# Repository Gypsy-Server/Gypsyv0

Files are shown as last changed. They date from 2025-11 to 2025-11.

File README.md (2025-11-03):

  
*A local file viewer built on the ESP8266*

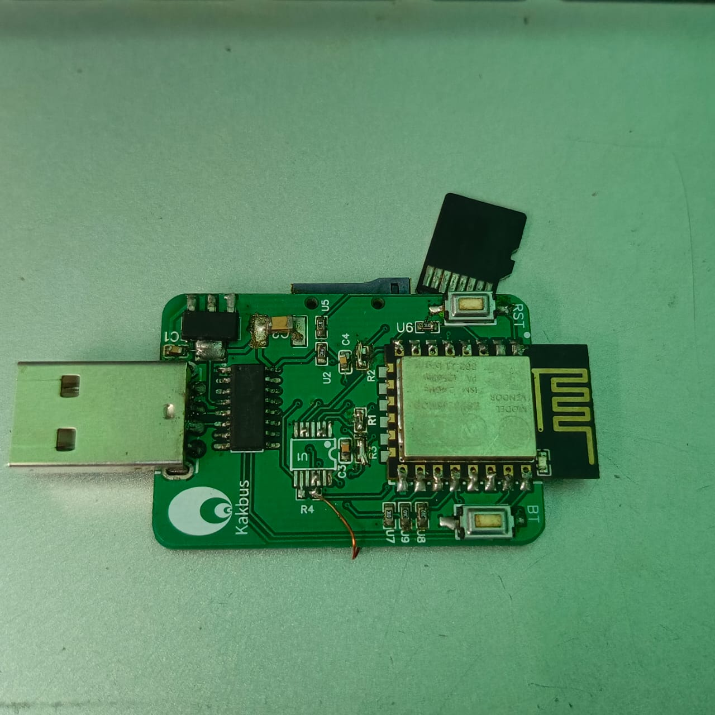
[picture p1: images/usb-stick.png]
Board Preview


---

## What is here

- **Local file browsing** over Wi-Fi  
- **SD card (FAT32/MBR)** storage support   
- Runs standalone — powered via USB or external 5 V  or 3.3V

---

## Hardware

- **MCU:** ESP8266(12E)
- **Storage:** SD card(SPI MODE)  
- **Voltage Regulator AMS117 3.3V**
- **Ch340C USB TO TTL Converter chip**
- **Passive Components:** Resistor ,Capacitor

You can view the full schematic and PCB in the `usb_stick_kicadfiles/` folder (KiCad project).

---

##  What to do 

1. Flash gypsy.ino using Arduino IDE or PlatformIO.  
2. Open Serial Monitor to get the IP (eg 192.168.x.x)
3. Open in any browser on Computer or any device connected to that Network

---
## What you will see

Home Page
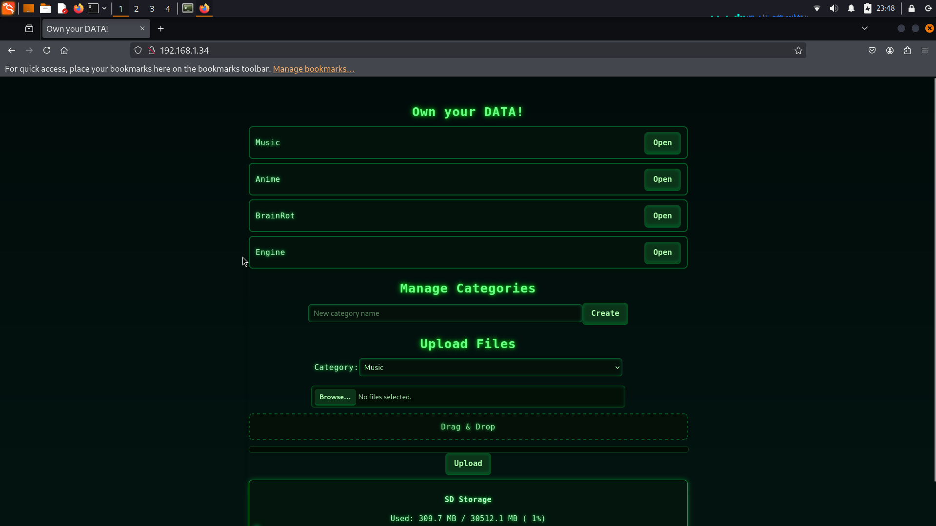
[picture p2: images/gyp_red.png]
Home Page


File viewing 
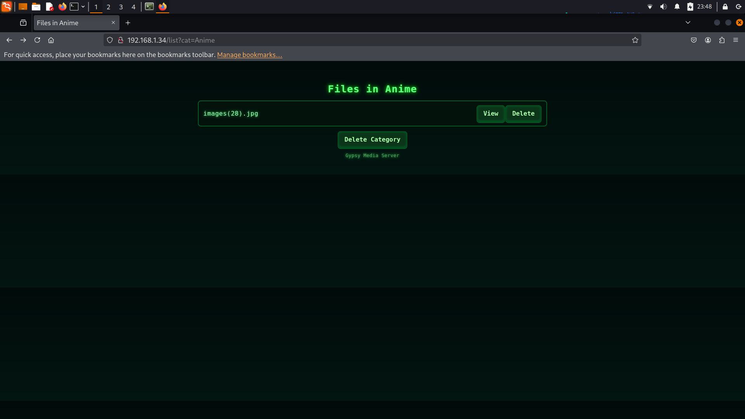
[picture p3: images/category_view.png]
File Handling

 
 Contents
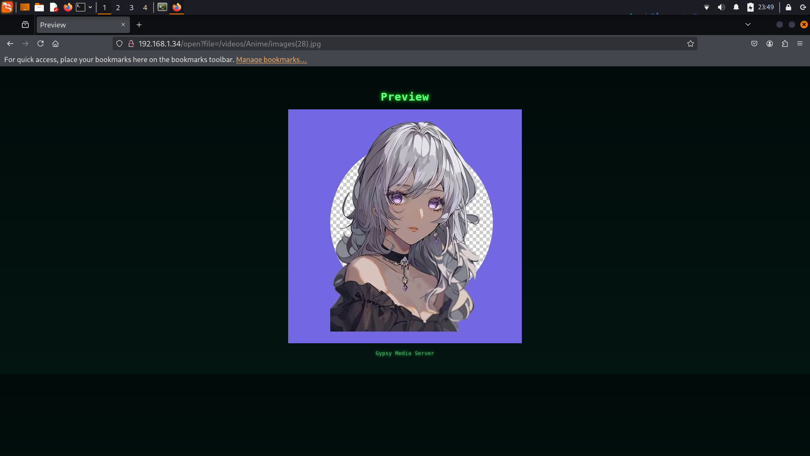
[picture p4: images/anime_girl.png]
Anime girl

 
 Mp4 full screen view
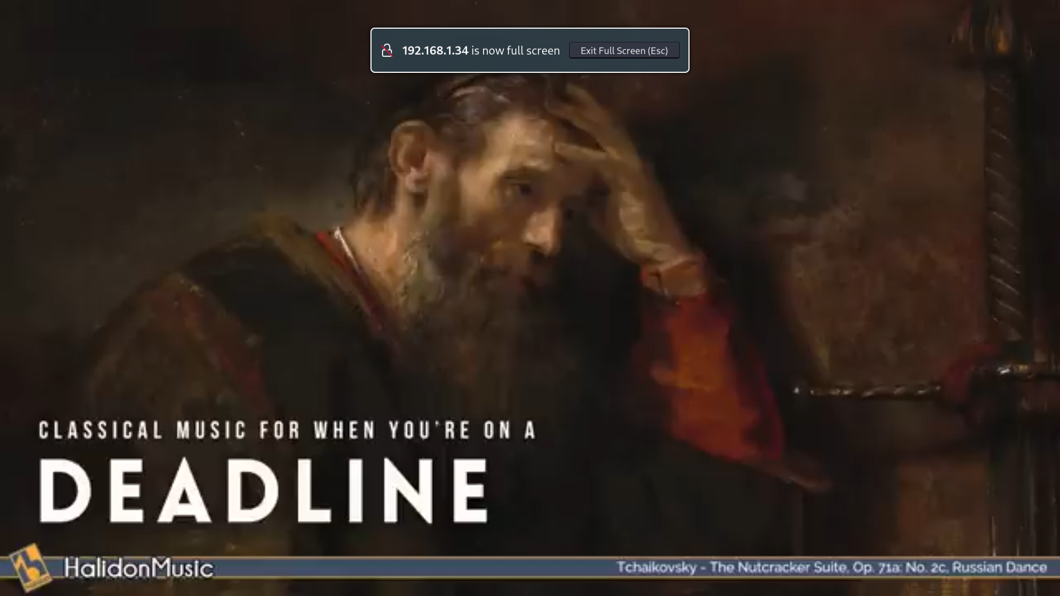
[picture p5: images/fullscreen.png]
Full screen Mp3


## What i have seen SO FAR
- file uploading speed is Limited (average 150-250KB/s)
- Slower playing Larger files (greater than 50MB)
- but Good in MP3 handling , doesn't stuck (80KB of RAM is sufficient in ths case)
- Sometimes SD card initialization fails (random)

## Some Fatal Issues 
- **The original PCB has fatal a flaw, SD card Chip detect Pin as CS PIN , so don't use this project as it is , Also the Driver chip of sd card is 
not necessary so for better design remove it esp8266 can drive sd card itself by 3.3v logic, for my case i have used and extra thin wire
to cover up my mistake**
so i would recommend to use this project [Hackstar-io](https://www.hackster.io/Neutrino-1/wireless-sd-card-reader-esp8266-de7f07)
for the Hardware Layout

**Mistakes**
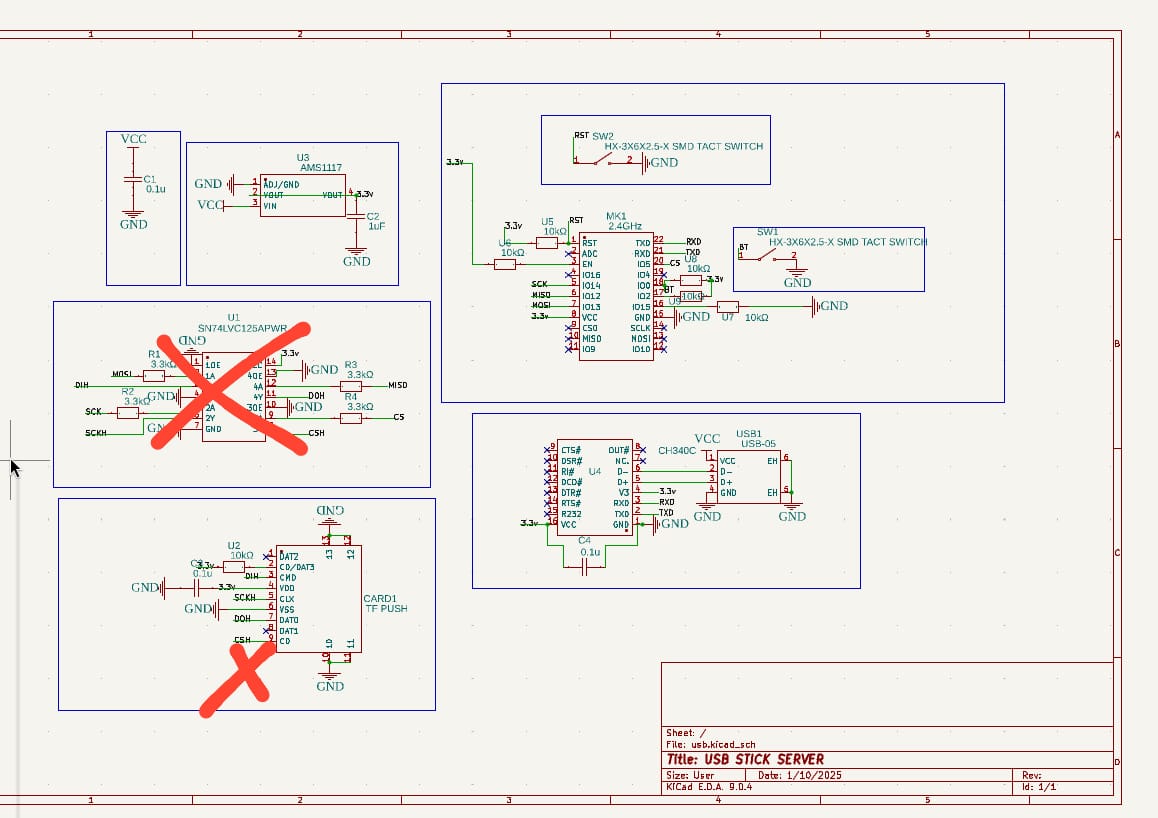
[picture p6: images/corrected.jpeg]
Wrong Schematic


##  What I’m Exploring Next

- Network sharing (I have tested it with Ngrok proxy tunneling to my friends , but if multiple people use at same time then it stops)  
- ESP32 port for faster WIFI throughput  
- Power optimization and case design( even smaller any small processor like Raspberry Pi Zero or ESP32 higher variant)
- Larger Video playback(cinema of Some Sort)

---

##  Feedback Wanted

This is still a **work in progress**, and I’d love your thoughts on:

- Firmware structure and web interface flow  
- PCB layout or power-handling tips  
- Ideas for extending it into a full mini NAS

If you’ve built anything similar — or see a way to make this smarter, faster, or cleaner — I’m all ears.

---

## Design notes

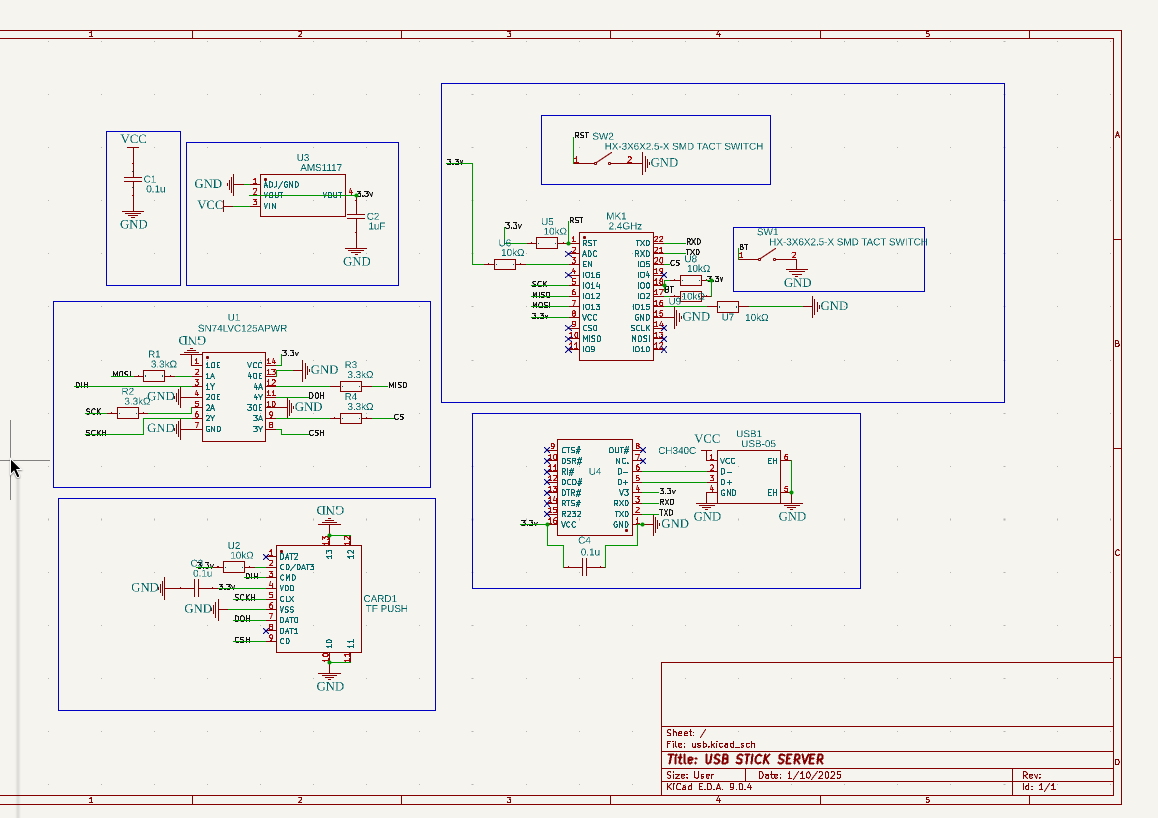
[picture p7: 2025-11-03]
images/usbstick.png

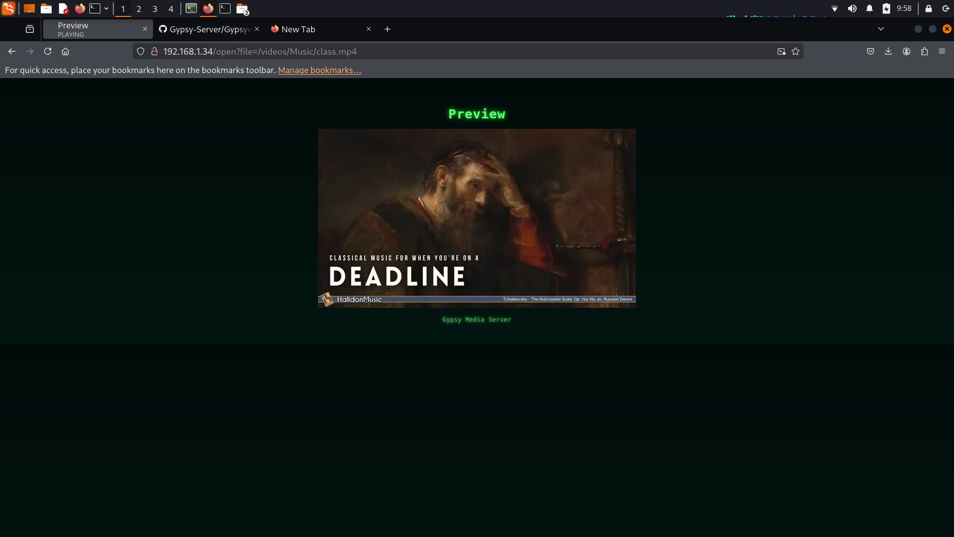
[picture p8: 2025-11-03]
images/mp4_playing.png

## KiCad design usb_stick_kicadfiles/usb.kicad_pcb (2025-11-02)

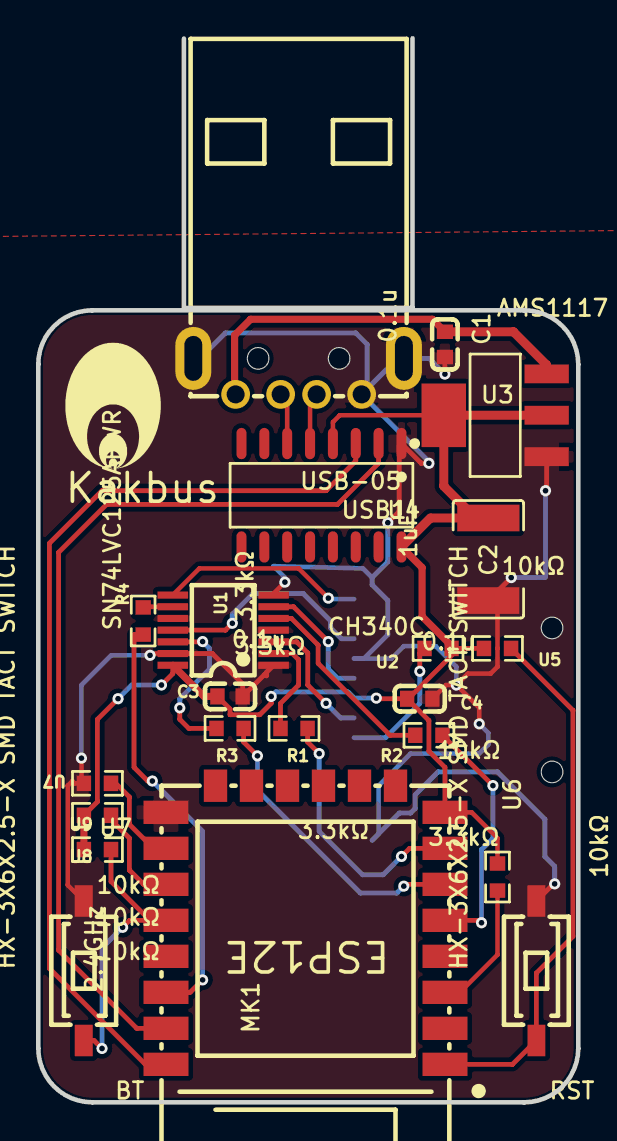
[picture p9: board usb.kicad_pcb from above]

Board: 2 copper layers, 30.0 x 44.0 mm, 22 parts (1 on the bottom side), 25 nets.

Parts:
BT: HX-3X6X2.5-X SMD TACT SWITCH; SW-SMD_HX-3X6X2.5-X
C1, C3, C4: 0.1u; C0603
C2: 1uF; C1812
CARD1: TF PUSH; TF-SMD_TF-PUSH
MK1: 2.4GHz; WIFIM-SMD_ESP-12E-BR
R1, R2, R3, R4: 3.3kΩ; R0603
RST: HX-3X6X2.5-X SMD TACT SWITCH; SW-SMD_HX-3X6X2.5-X
U1: SN74LVC125APWR; TSSOP-14_L5.0-W4.4-P0.65-LS6.4-BL
U2, U5, U6, U7, U8, U9: 10kΩ; R0603
U3: AMS1117; SOT-223_L6.5-W3.5-P2.30-LS7.0-BR
U4: CH340C; SOP-16_L10.0-W3.9-P1.27-LS6.0-BL
USB1: USB-05; USB-A-TH_USB-05

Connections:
3.3V: C2.2, C3.1, C4.1, CARD1.4, MK1.8, U1.14, U2.1, U3.2, U3.4, U4.4, U4.16, U5.1, U6.1, U8.2, U9.2
BT: BT.1, MK1.18, U8.1
CARD1_2: CARD1.2, U2.2
CS: MK1.20, R4.2
CSH: CARD1.CD, U1.8
DIH: CARD1.3, U1.3
DOH: CARD1.7, U1.11
GND: BT.2, C1.1, C2.1, C3.2, C4.2, CARD1.6, CARD1.10, CARD1.11, CARD1.12, CARD1.13, MK1.15, RST.2, U1.1, U1.4, U1.7, U1.10, U1.13, U3.1, U4.1, U7.2, USB1.4, USB1.5, USB1.6
MISO: MK1.6, R3.2
MK1_3: MK1.3, U6.2
MK1_16: MK1.16, U7.1
MK1_17: MK1.17, U9.1
MOSI: MK1.7, R1.1
RST: MK1.1, RST.1, U5.2
RXD: MK1.22, U4.3
SCK: MK1.5, R2.1
SCKH: CARD1.5, U1.6
TXD: MK1.21, U4.2
U1_2: R1.2, U1.2
U1_5: R2.2, U1.5
U1_9: R4.1, U1.9
U1_12: R3.1, U1.12
U4_5: U4.5, USB1.3
U4_6: U4.6, USB1.2
VCC: C1.2, U3.3, USB1.1

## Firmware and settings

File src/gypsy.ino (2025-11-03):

/*
 * Gypsy version 0 (basic version), open for everyone to try and give a feedback
 * 
 * 
 * 
 * 
 * 
 * 
 * Using SD card as a Fat32 File System to store content , And accessing it through our local network via ESP8266 in DHCP mode 
Router is necessary , If you don't have router then There will be a Access point mode version 
 * format sd card to FAT32 MBR before using it

It was originally a Platformio project , converted in a single file for quick upload and test
 */


#include <ESP8266WiFi.h>
#include <ESP8266WebServer.h>
#include <SdFat.h>

#define SD_CS_PIN 5 //IF YOU HAVE ANY OTHER SPARE GPIO USE THAT 

const char* ssid = "Enter your Network id here";
const char* password = "your network password";

ESP8266WebServer server(80);
SdFat32 SD;

volatile bool isClientStreaming = false;
volatile bool isUploading = false;
File32 upFile; 

String cleanName(String s) {
  s.replace("..", "");
  while (s.startsWith("/")) s.remove(0, 1);
  while (s.endsWith("/")) s.remove(s.length() - 1);
  const char bad[] = {'\\','/','?','%','*',':','|','"','<','>','\''};
  for (char c : bad) s.replace(String(c), "_");
  return s;
}

const char* getMimeType(const String &n) {
  String ln = n; ln.toLowerCase();
  if (ln.endsWith(".mp4")) return "video/mp4";
  if (ln.endsWith(".mkv")) return "video/x-matroska";
  if (ln.endsWith(".webm")) return "video/webm";
  if (ln.endsWith(".avi")) return "video/x-msvideo";
  if (ln.endsWith(".ogg")) return "video/ogg";
  if (ln.endsWith(".jpg") || ln.endsWith(".jpeg")) return "image/jpeg";
  if (ln.endsWith(".png")) return "image/png";
  if (ln.endsWith(".gif")) return "image/gif";
  if (ln.endsWith(".webp")) return "image/webp";
  if (ln.endsWith(".pdf")) return "application/pdf";
  if (ln.endsWith(".txt")) return "text/plain";
  return "application/octet-stream";
}
uint64_t getDirSize(const char *path) {
  uint64_t total = 0;
  File32 dir = SD.open(path);
  if (!dir) return 0;
  if (!dir.isDir()) {
    total = dir.size();
    dir.close();
    return total;
  }

  File32 entry;
  while ((entry = dir.openNextFile())) {
    char name[128];
    entry.getName(name, sizeof(name));
    if (entry.isDir()) {
      String sub = String(path);
      if (!sub.endsWith("/")) sub += "/";
      sub += String(name);
      total += getDirSize(sub.c_str());
    } else {
      total += entry.size();
    }
    entry.close();
    yield();
  }
  dir.close();
  return total;
}


void htmlHead(const String &title) {
  server.setContentLength(CONTENT_LENGTH_UNKNOWN);
  server.send(200, "text/html", "");
  server.sendContent(F(
    "<!DOCTYPE html><html><head><meta charset='utf-8'><meta name='viewport' content='width=device-width,initial-scale=1'>"
    "<style>"
    "body{margin:0;font-family:'Lucida Console',monospace;background:#020607;color:#bdf6c6;"
    "font-size:16px;letter-spacing:0.5px;text-shadow:0 0 6px #0f4;"
    "background-image:linear-gradient(180deg,#010b0a 0%,#031511 100%);}"
    ".wrap{max-width:900px;margin:18px auto;padding:12px;text-align:center}"
    "h3{color:#6aff82;font-size:1.6em;text-shadow:0 0 10px #0f0,0 0 4px #063;"
    "letter-spacing:1px;margin-bottom:14px}"
    ".item{background:#03130c;border:2px solid #065a2a;border-radius:8px;"
    "margin:8px 0;padding:10px 12px;display:flex;justify-content:space-between;align-items:center;"
    "box-shadow:0 3px 12px rgba(0,20,0,0.6);transition:all 0.2s ease}"
    ".item:hover{background:#052512;border-color:#08b43a;box-shadow:0 4px 16px rgba(0,100,0,0.8)}"
    "form{margin:12px 0;}"
    "input[type=text],select{background:#041009;border:1px solid #0b5a2a;border-radius:6px;"
    "color:#aefcb6;padding:8px 10px;font-size:0.95em;outline:none;width:60%;"
    "box-shadow:inset 0 0 6px #053;transition:all 0.2s ease}"
    "input[type=text]:focus,select:focus{border-color:#0f5;box-shadow:0 0 8px #0f5}"
    "input[type=file]{color:#9fd9a2;background:#031006;border:1px solid #094a1c;border-radius:6px;"
    "padding:6px;font-size:0.9em;cursor:pointer;width:70%;box-shadow:inset 0 0 6px #042}"
    "input[type=file]::file-selector-button{background:#0b3418;color:#afffaf;border:none;padding:6px 10px;"
    "border-radius:6px;font-weight:bold;cursor:pointer;box-shadow:0 3px 0 #052;transition:0.2s}"
    "input[type=file]::file-selector-button:hover{background:#0f5;color:#021;box-shadow:0 0 10px #0f5}"
    "button,input[type=submit]{background:#0b3418;color:#afffaf;border:2px solid #094a1c;"
    "padding:10px 16px;border-radius:8px;font-weight:bold;font-size:1em;cursor:pointer;"
    "box-shadow:0 3px 0 #052,inset 0 0 6px #063;transition:0.2s;font-family:'Lucida Console',monospace}"
    "button:hover,input[type=submit]:hover{background:#00cc55;border-color:#0b0;color:#021;"
    "box-shadow:0 0 10px #00ff80,inset 0 0 8px #0f5;transform:translateY(-1px)}"
    ".newcat{background:#083518;border:2px solid #0a4;color:#bdf6c6;font-weight:bold;"
    "padding:10px 18px;border-radius:8px;box-shadow:0 0 10px #063,inset 0 0 5px #0a4;"
    "transition:all 0.2s ease;cursor:pointer}"
    ".drop{margin:12px 0;padding:16px;border:2px dashed #0b5a2a;border-radius:8px;"
    "background:#041008;color:#9fd9a2;transition:all 0.2s ease}"
    ".drop.dragover{background:#072a14;box-shadow:0 0 16px #0f5}"
    ".progress{width:100%;height:12px;background:#010b04;border:1px solid #083b18;border-radius:6px;margin-top:10px}"
    ".bar{height:100%;background:linear-gradient(90deg,#00ff88,#008844);width:0%;border-radius:6px;box-shadow:0 0 10px #00ff88}"
    "#sdinfo{background:#03150c;border:1px solid #0a4;border-radius:8px;padding:10px;margin:10px 0;"
    "box-shadow:0 0 10px #062;color:#bdf6c6;font-size:0.95em;text-shadow:0 0 6px #0f4;}"
    "@media(max-width:500px){body{font-size:15px}.item{flex-direction:column;align-items:flex-start}}"
    "</style><title>"
  ));
  server.sendContent(title + "</title></head><body><div class='wrap'><h3>" + title + "</h3>");
}

void htmlEnd() {
  server.sendContent(F("<p style='font-size:12px;color:#6f9f6f'>Gypsy Media Server</p></div></body></html>"));
}


void streamFile(File32 &f, const char *type) {
  WiFiClient c = server.client();
  server.setContentLength(f.size());
  server.send(200, type, "");
  uint8_t buf[1024];
  while (f.available() && c.connected()) {
    size_t n = f.read(buf, sizeof(buf));
    if (n) c.write(buf, n);
    yield();
  }
  f.close(); c.flush(); c.stop();
}

bool delRecursive(const String &p) {
  File32 d = SD.open(p.c_str());
  if (!d || !d.isDir()) { if (d) d.close(); return false; }
  File32 e; char n[64];
  while ((e = d.openNextFile())) {
    e.getName(n, sizeof(n));
    String name = p + "/" + String(n);
    if (e.isDir()) delRecursive(name);
    else SD.remove(name.c_str());
    e.close(); yield();
  }
  d.close(); SD.rmdir(p.c_str());
  return true;
}
void handleRoot() {
  File32 root = SD.open("/videos");
  if (!root || !root.isDir()) {
    server.send(200, "text/html", "<h3>/videos missing</h3>");
    return;
  }

  htmlHead("Own your DATA!");

  File32 e; char n[64];
  while ((e = root.openNextFile())) {
    if (e.isDir()) {
      e.getName(n, sizeof(n));
      server.sendContent(
        "<div class='item'><span class='fname'>" + String(n) + 
        "</span><a href='/list?cat=" + String(n) + "'><button>Open</button></a></div>");
    }
    e.close();
    yield(); 
  }

  server.sendContent(F(
    "<div class='card'><h3>Manage Categories</h3>"
    "<form id='createForm'><input name='cat' placeholder='New category name' type='text'>"
    "<input type='submit' value='Create' class='newcat'></form></div>"
    "<div class='card'><h3>Upload Files</h3>"
    "<form id='upForm' enctype='multipart/form-data'>"
    "<label>Category:</label><select name='category' id='catSel'></select><br><br>"
    "<input type='file' name='file' multiple><div id='drop' class='drop'>Drag & Drop</div>"
    "<div class='progress' id='prog'><div class='bar' id='bar'></div></div>"
    "<input type='submit' value='Upload' class='newcat'></form></div>"
    "<script>var s=document.getElementById('catSel');"
  ));

  root.rewind();
  while ((e = root.openNextFile())) {
    if (e.isDir()) {
      e.getName(n, sizeof(n));
      server.sendContent("s.innerHTML+='<option value=\"" + String(n) + "\">" + String(n) + "</option>';"); 
    }
    e.close();
    yield();
  }

  server.sendContent(F(
    "var drop=document.getElementById('drop'),bar=document.getElementById('bar'),prog=document.getElementById('prog');"
    "function send(fd,cat){var x=new XMLHttpRequest();x.open('POST','/upload?cat='+encodeURIComponent(cat));"
    "x.upload.onprogress=function(e){if(e.lengthComputable){prog.style.display='block';bar.style.width=(e.loaded/e.total*100)+'%';}};"
    "x.onload=function(){location.reload();};x.send(fd);}"
    "document.getElementById('upForm').onsubmit=function(e){e.preventDefault();var fd=new FormData(this);send(fd,this.category.value);};"
    "drop.ondragover=function(e){e.preventDefault();drop.classList.add('dragover');};"
    "drop.ondragleave=function(e){drop.classList.remove('dragover');};"
    "drop.ondrop=function(e){e.preventDefault();drop.classList.remove('dragover');var fd=new FormData();"
    "for(var f of e.dataTransfer.files)fd.append('file',f);send(fd,document.getElementById('catSel').value);};"
    "document.getElementById('createForm').onsubmit=function(e){e.preventDefault();var n=this.cat.value.trim();if(!n)return;"
    "fetch('/create?cat='+encodeURIComponent(n),{method:'POST'}).then(()=>location.reload());};"
    "</script>"
  ));
  server.sendContent(F(
    "<div id='sdinfo' class='card'>Loading SD info...</div>"
    "<script>fetch('/sdinfo').then(r=>r.text()).then(t=>{document.getElementById('sdinfo').innerHTML=t;})"
    ".catch(()=>{document.getElementById('sdinfo').innerHTML='SD info unavailable';});</script>"
  ));

  htmlEnd();
  root.close();
}

void handleCreate() {
  if (isUploading || isClientStreaming) { server.send(503, "text/plain", "Busy"); return; }
  String c = cleanName(server.arg("cat"));
  if (c.length()) {
    String p = "/videos/" + c;
    if (!SD.exists(p.c_str())) SD.mkdir(p.c_str());
  }
  server.sendHeader("Location", "/");
  server.send(303);
}

void handleList() {
  String cat = cleanName(server.arg("cat"));
  String path = "/videos/" + cat;
  File32 dir = SD.open(path.c_str());
  if (!dir || !dir.isDir()) { server.send(404, "text/plain", "Not found"); return; }

  htmlHead("Files in " + cat);

  File32 f; char n[64];
  while ((f = dir.openNextFile())) {
    if (!f.isDir()) {
      f.getName(n, sizeof(n));
      String nm = String(n), fp = path + "/" + nm;
      server.sendContent("<div class='item'><div class='fname'>" + nm + "</div>"
                         "<div><a href='/open?file=" + fp + "'><button>View</button></a>"
                         "<form method='POST' action='/delfile' style='display:inline'><input type='hidden' name='file' value='" + fp + "'>"
                         "<input type='submit' value='Delete'></form></div></div>");
    }
    f.close();
    yield();
  }

  server.sendContent("<form method='POST' action='/delcat'><input type='hidden' name='cat' value='" + cat + "'><input type='submit' value='Delete Category'></form>");
  htmlEnd();
  dir.close();
}

void handleOpen() {
  String f = server.arg("file");
  if (!SD.exists(f.c_str())) { server.send(404, ""); return; }
  htmlHead("Preview");
  String lf = f; lf.toLowerCase();
  if (lf.endsWith(".mp4") || lf.endsWith(".mkv") || lf.endsWith(".webm"))
    server.sendContent("<video controls autoplay><source src='/stream?file=" + f + "'></video>");
  else if (lf.endsWith(".jpg") || lf.endsWith(".png") || lf.endsWith(".gif") || lf.endsWith(".webp"))
    server.sendContent("<img src='/stream?file=" + f + "'>");
  else
    server.sendContent("<iframe src='/stream?file=" + f + "' style='height:70vh;border:none'></iframe>");
  htmlEnd();
}

void handleStream() {
  if (isUploading || isClientStreaming) { server.send(503, "text/plain", "Busy"); return; }
  String p = server.arg("file");
  if (!SD.exists(p.c_str())) { server.send(404, "Not found"); return; }

  File32 f = SD.open(p.c_str(), FILE_READ);
  const char* mime = getMimeType(p);
  server.sendHeader("Content-Disposition", "inline; filename=\"" + p.substring(p.lastIndexOf('/') + 1) + "\"");
  server.sendHeader("Cache-Control", "max-age=3600");
  isClientStreaming = true;
  streamFile(f, mime);
  isClientStreaming = false;
}

void handleDelCat() {
  if (isUploading || isClientStreaming) { server.send(503, "Busy"); return; }
  String c = cleanName(server.arg("cat"));
  delRecursive("/videos/" + c);
  server.sendHeader("Location", "/");
  server.send(303);
}

void handleDelFile() {
  if (isUploading || isClientStreaming) { server.send(503, "Busy"); return; }
  String f = server.arg("file");
  SD.remove(f.c_str());
  server.sendHeader("Location", "/");
  server.send(303);
}

void handleUploadData() {
  HTTPUpload &u = server.upload();
  if (u.status == UPLOAD_FILE_START) {
    String cat = cleanName(server.arg("cat"));
    if (!cat.length()) cat = "default";
    String folder = "/videos/" + cat;
    if (!SD.exists(folder.c_str())) SD.mkdir(folder.c_str());
    String path = folder + "/" + cleanName(u.filename);
    isUploading = true;
    upFile = SD.open(path.c_str(), O_WRONLY | O_CREAT | O_TRUNC);
  } else if (u.status == UPLOAD_FILE_WRITE) {
    if (upFile) upFile.write(u.buf, u.currentSize);
  } else if (u.status == UPLOAD_FILE_END || u.status == UPLOAD_FILE_ABORTED) {
    if (upFile) upFile.close();
    isUploading = false;
  }
}

void handleSdInfo() { // to get the storage information 

  uint64_t usedBytes = getDirSize("/videos");
  float usedMB = usedBytes / (1024.0 * 1024.0);

  String html;
  html.reserve(256);
  html += "<h4>SD Storage</h4>";
  html += "Used: " + String(usedMB, 1) + " MB";

  FatVolume* vol = SD.vol();
  if (vol) {
    uint32_t totalClusters = vol->clusterCount();
    if (totalClusters == 0) {
      html += "<br>Total: unknown";
      html += "<div class='progress' style='margin-top:6px;'><div class='bar' style='width:0%'></div></div>";
    } else {
      float bytesPerCluster = vol->bytesPerCluster();
      float totalMB = (totalClusters * bytesPerCluster) / (1024.0 * 1024.0);
      float pct = (totalMB > 0.0) ? ((usedMB / totalMB) * 100.0) : 0.0;
      html += " / " + String(totalMB, 1) + " MB";
      html += " (" + String(pct, 0) + "%)";
      html += "<div class='progress' style='margin-top:6px;'><div class='bar' style='width:" + String(pct) + "%'></div></div>";
    }
  } else {
    html += "<br>Total: unknown";
    html += "<div class='progress' style='margin-top:6px;'><div class='bar' style='width:0%'></div></div>";
  }

  server.send(200, "text/html", html);
}


void setup() {
  Serial.begin(115200);
  WiFi.begin(ssid, password);
  Serial.print("getting into the connection...");
  while (WiFi.status() != WL_CONNECTED) { delay(400); Serial.print("."); }
  Serial.println("\nIP: " + WiFi.localIP().toString());

  if (!SD.begin(SD_CS_PIN, SD_SCK_MHZ(25))) {
    Serial.println("SD is failing bro please scratch it or format it to FAT32 MBR before using it"); while (1) delay(1000);
  }
  if (!SD.exists("/videos")) SD.mkdir("/videos");

  server.on("/", HTTP_GET, handleRoot);
  server.on("/create", HTTP_POST, handleCreate);
  server.on("/list", HTTP_GET, handleList);
  server.on("/open", HTTP_GET, handleOpen);
  server.on("/stream", HTTP_GET, handleStream);
  server.on("/delcat", HTTP_POST, handleDelCat);
  server.on("/delfile", HTTP_POST, handleDelFile);
  server.on("/upload", HTTP_POST, []() { server.send(200); }, handleUploadData);
  server.on("/sdinfo", handleSdInfo);

  server.begin();
  Serial.println("HTTP server ready");
}

void loop() { server.handleClient(); yield(); }

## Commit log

2025-11-02 kicad files , have a fatal error , i have put chip detect pin as CS haha
    [usb.kicad_sch]
2025-11-03 removed old files
    [usb.kicad_pcb, usb.kicad_sch]
